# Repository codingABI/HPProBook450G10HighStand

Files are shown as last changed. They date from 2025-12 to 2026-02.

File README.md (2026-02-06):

# HPProBook450G10HighStand
A DIY stand for a HP ProBook 450 G10 notebook, which was built from [3d prints](#STL) and some metal parts from a hardware store. The high side of the stand is 13cm high (With rubber feet attached to the bottom) and lifts my notebook display to the same level as my external monitors.

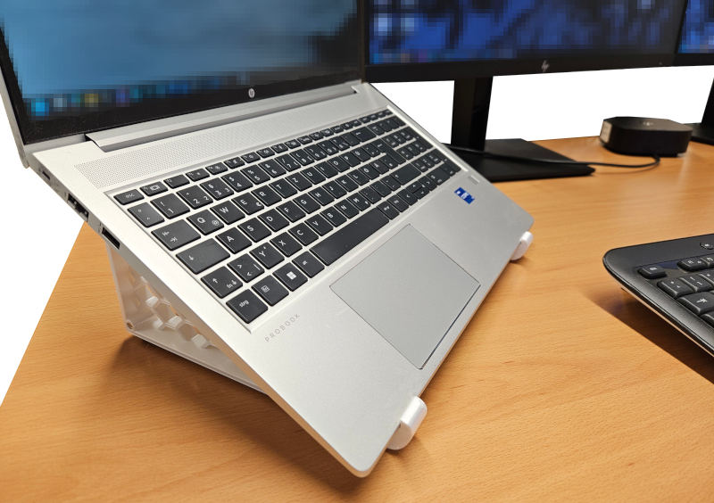
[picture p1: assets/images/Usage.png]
Usage


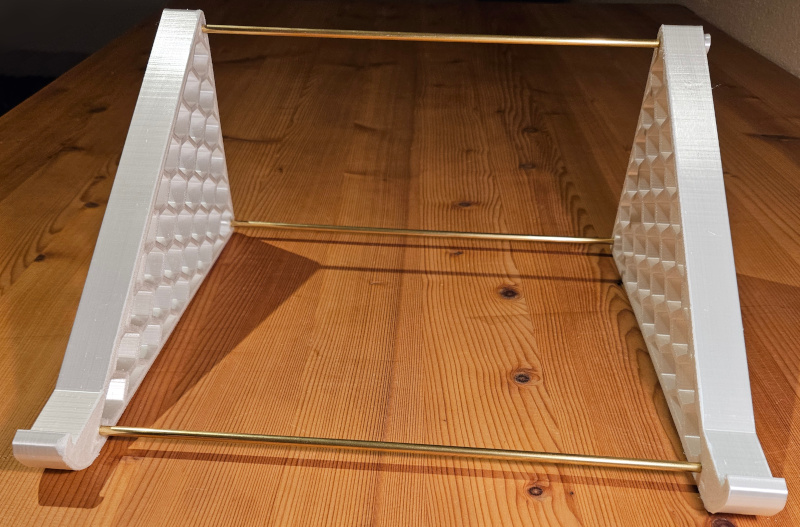
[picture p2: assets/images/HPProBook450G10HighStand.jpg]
Front view


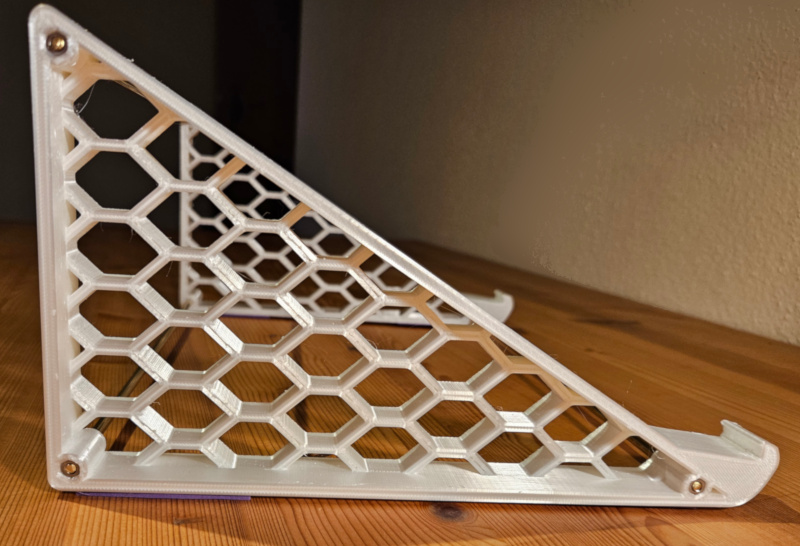
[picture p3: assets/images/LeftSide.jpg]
Left side


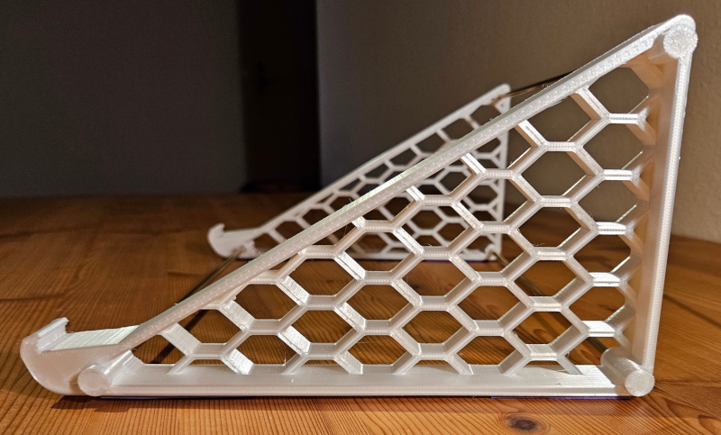
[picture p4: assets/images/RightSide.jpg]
Right side


| Property  | Value | Note |
| --- | --- | --- |
| Height  | 13cm  | |
| Width  | 28.4cm  | Could be changed with different [metal parts](#metal-parts) |
| Deepth  | 22.1cm  | |
| Weight  | 225g | 3d PLA prints ~156g |

## License and copyright
My [3d STL print files](#STL) are licensed under the terms of CC0 [Copyright (c) 2025 codingABI](LICENSE). 

## Appendix

### Metal parts

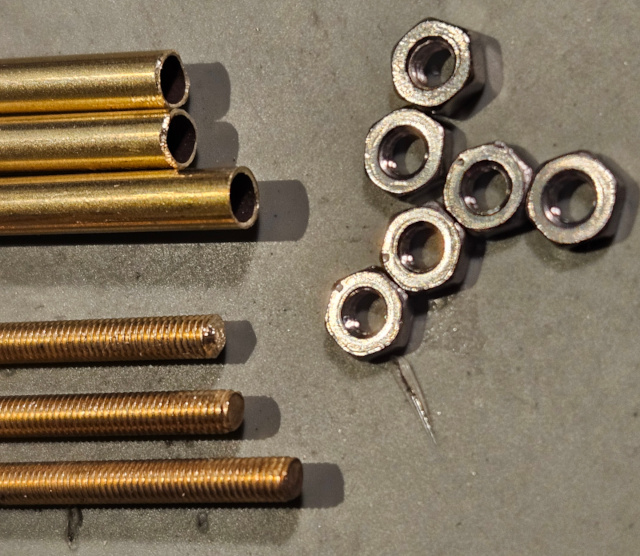
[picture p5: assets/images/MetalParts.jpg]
Metal parts


- 3x brass tubes (Outer diameter 4.0mm, inner diameter >= 3.0mm)
- 3x brass M3 threaded rods with the length of one brass tube plus 2.3cm
- 6x M3 nuts

I used brass tubes with a length of 26cm, but you can use other lengths. The threaded rods are sticked in the brass tubes. 

If the threaded rods do not fit through the holes in the 3d printed side parts, the printed holes should be re-drilled with a 3.0 mm drill bit.

The M3 nuts on
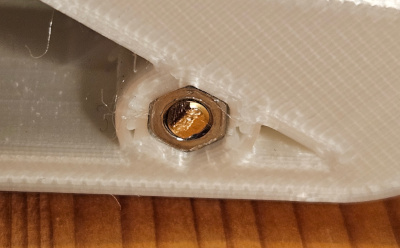
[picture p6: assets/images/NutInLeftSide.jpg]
Nut in left side
- the left side will be pressed in the place holders of the [3d left side print](STL/HPProBook450G10HighStandLeftSide.stl). To prevent the threaded rod from turning, the last half millimeter of the threaded rod on the left side was hammered into the nut before the threaded rod and nut were installed in the 3d print. (Gluing the threaded rod to the nut on the left side should also work). <br /> 
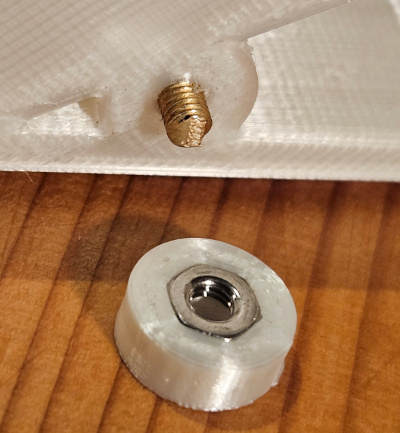
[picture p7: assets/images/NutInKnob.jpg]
Nut in knob
- the right side will be pressed the place holders of the three [3d knob prints](STL/HPProBook450G10HighStandKnob.stl) <br />

### STL

- [Left side](STL/HPProBook450G10HighStandLeftSide.stl)
- [Right side](STL/HPProBook450G10HighStandRightSide.stl)
- [Knob](STL/HPProBook450G10HighStandKnob.stl) (Three printed knobs are needed)

All STL files were created and designed with Tinkercad https://www.tinkercad.com

Printer settings used on my Anycubic Vyper (Thank you **https://github.com/m-holler**!): 
- Nozzle: 0.4mm
- Layer height: 0.15mm
- Filament: PLA+ silk

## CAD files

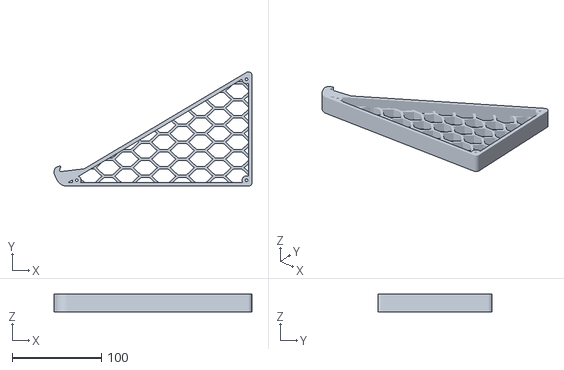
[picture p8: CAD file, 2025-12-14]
STL/HPProBook450G10HighStandRightSide.stl
221.6 x 128.0 x 20.0

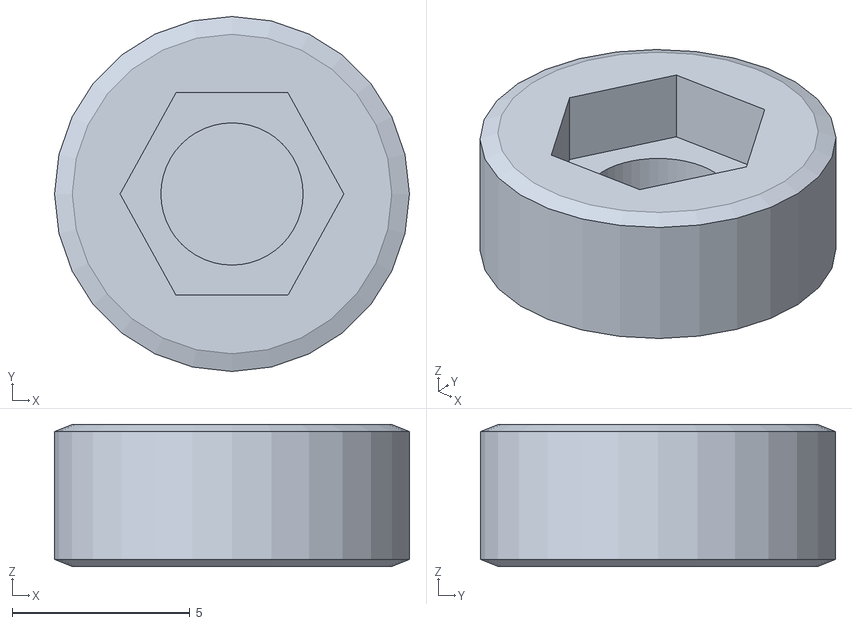
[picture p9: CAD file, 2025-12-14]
STL/HPProBook450G10HighStandKnob.stl
10.0 x 10.0 x 4.00

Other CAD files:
STL/HPProBook450G10HighStandLeftSide.stl

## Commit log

2026-02-06 Update README with M3 nut installation details
    Clarified installation instructions for M3 nuts on both sides, including additional details on securing the threaded rod.
2026-02-06 Update installation instructions in README.md
    Clarified instructions for installing the threaded rod and nut on the left side, including an alternative gluing method.
